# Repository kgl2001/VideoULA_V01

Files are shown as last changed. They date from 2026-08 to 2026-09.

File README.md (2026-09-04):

# VideoULA V01 — BBC Micro Video ULA Replacement
## 44-pin Xilinx XC9572XL CPLD Version

This repository contains the hardware design and firmware for the VideoULA V01, a drop-in replacement for the VC2069 Video ULA (IC6) in the Acorn BBC Micro Model B.

---

## Project Overview

The original BBC Micro Video ULA (IC6) is a custom ASIC that is no longer manufactured. Failed or missing ULAs result in a non-functional machine. This project provides a modern replacement using a CPLD and a small external SRAM for palette storage.

There are three hardware versions of this replacement, each in a separate repository:

| Version | CPLD | Macrocells | Tool | Repository |
|---|---|---|---|---|
| **V01** | Xilinx XC9572XL-10-VQ44 | 72 | ISE 14.7 | This repo |
| V02 | Xilinx XC9572XL-10-VQ64 | 72 | ISE 14.7 | [VideoULA_V02](https://github.com/kgl2001/VideoULA_V02) |
| V03 | Atmel ATF1504AS-10AU44 | 64 | Quartus 13.0 SP1 | [VideoULA_V03](https://github.com/kgl2001/VideoULA_V03) |

All three versions share the same 28-pin DIP footprint as the original ULA and are pin-compatible with the BBC Micro motherboard.

---

## V01 Hardware

- **CPLD**: Xilinx XC9572XL-10-VQ44 (72 macrocells, 3.3V core, 5V tolerant I/O)
- **SRAM**: ISSI IS62C256AL-45TLI (32K×8, 5V, TSOP-28, 45ns) — only locations 0-15 and bits 0-3 used
- **Oscillator**: 48MHz SMD oscillator (3225 package, 5V) — for 48MHz operating mode only
- **LDO**: XC6206P332MR (SOT-23, 3.3V) — powers CPLD core

### Hardware Revisions

| Revision | Status | Changes |
|---|---|---|
| Rev01 | Built and tested | Initial release |
| Rev02 | PCB designed, not yet built | Added 47Ω series resistor and 74LVC1G17 Schmitt trigger buffer on CLK_IN; CPLD pin assignments updated |
| Rev03 | PCB designed, not yet built | Added 74LV6T17 to buffer all clock outputs (8/4/2/1MHz, CRTC) for Master 128 compatibility |
| Rev04 | PCB designed, not yet built | Repositioned JTAG header |

Note: Only Rev01 has been built and tested. Rev02 onwards incorporate improvements identified during Rev01 testing.

### CLK_IN Reliability Daughterboard

During testing of Rev01 on BBC Micro machines with the original 16MHz clock circuit, some machines showed reliability issues in 16MHz operating mode — particularly on cold startup. Investigation revealed that the BBC's 16MHz crystal oscillator circuit produces a noisy clock signal that the CPLD occasionally misinterprets as spurious edges, causing display glitches.

To address this without waiting for a new PCB revision, a small standalone buffer board was developed. This daughterboard:

- Plugs into the BBC Micro motherboard in place of the VideoULA V01
- The VideoULA V01 then plugs into the daughterboard
- Intercepts the 16MHz clock signal from the BBC motherboard
- Passes it through a 47Ω series resistor and 74HCT14E Schmitt trigger buffer before it reaches the CPLD
- Passes all other signals through unchanged

The 74HCT14E was chosen as a through-hole part for ease of hand soldering. Rev02+ PCB designs use the smaller surface-mount 74LVC1G17 in conjunction with a series resistor to achieve the same signal conditioning in a more compact form.

This fix was confirmed to resolve the cold startup reliability issues on affected machines. The improvement has been incorporated into Rev02 of the V01 PCB and all subsequent hardware versions.

The daughterboard design files are included in this repository.

---

## Firmware

The firmware is written in Verilog and built using Xilinx ISE 14.7.

### Operating Modes

Two firmware builds are required — one per operating mode. To switch modes, reprogram the CPLD with the appropriate `.jed` file. A solder bridge on the PCB selects whether the 48MHz oscillator or the BBC's 16MHz clock is connected to the CPLD clock input.

#### 48MHz Mode (recommended)
- Uses the onboard 48MHz oscillator as the master clock
- Generates all BBC clock outputs (8/4/2/1MHz, CRTC, 6MHz) internally
- Provides clean, phase-locked 6MHz output for the SAA5050 teletext chip (tD ≈ 20ns ✓)
- Works reliably on all machines from cold power-up, including those with noisy clock circuits
- Build: uncomment `` `define CLK_48MHZ `` in `VideoULA.v`

#### 16MHz Mode
- Uses the BBC motherboard's 16MHz clock as the master clock
- No onboard oscillator required
- May show brief display noise on cold startup on machines with noisy 16MHz clock circuits
- The CLK_IN daughterboard resolves this on Rev01; Rev02+ has the fix built in
- Build: uncomment `` `define CLK_16MHZ `` in `VideoULA.v`

### ISE Fitter Settings (critical)

| Setting | Value | Notes |
|---|---|---|
| Implementation Template | **Optimise Speed** | Density causes timing failures at temperature |
| Macrocell Power | **Std** | Low Power prevents BBC from booting |
| Output Slew Rate | Fast | |
| Default Powerup Value | Low | |
| Pterms | **14** (16MHz build only) | Default 25 causes silent fit failure in 16MHz build |

### Build Instructions

1. Open Xilinx ISE 14.7
2. Create a new project targeting `XC9572XL-10-VQ44`
3. Add `src/VideoULA.v` and `src/VideoULA.ucf` to the project
4. Select the operating mode by uncommenting the appropriate `define` in `VideoULA.v`
5. Set fitter options as above
6. Run `Implement Design` to generate the `.jed` file
7. Program the CPLD using iMPACT or a compatible JTAG programmer

---

## SRAM Wiring

The external SRAM stores the 16-entry colour palette (4 bits per entry):

| SRAM Pin | Connection |
|---|---|
| A0-A3 | CPLD SRAM_ADDR[0:3] |
| A4-A14 | GND (tie low) |
| D0-D3 | CPLD SRAM_DATA[0:3] (bidirectional) |
| D4-D7 | Leave unconnected |
| /WE | CPLD SRAM_nWE |
| /OE | GND (always output enabled) |
| /CS | GND (always selected) |

---

## 6MHz Clock for Mode 7 (Teletext)

The SAA5050 teletext chip requires a 6MHz clock with a specific phase relationship to the 1MHz system clock (tD = 6-60ns from 6MHz rising edge to 1MHz falling edge).

- **48MHz mode**: The CPLD generates a clean, phase-locked 6MHz output on the CLK_6M pin (tD ≈ 20ns ✓). This can be connected to the SAA5050 via an IC37 replacement board.
- **16MHz mode**: The BBC motherboard's existing 6MHz generation circuit is used. The CPLD CLK_6M output is held high-Z.

---

## PCB Design Notes

The PCB has been designed using KiCAD V10 as a 2-layer board. It can easily be changed to a 4-layer board with GND/Power planes on the inner layers if signal integrity is a concern.

### JLCPCB Fabrication

The board design includes a 5×5mm silkscreen box on the underside of the PCB. This is used by JLCPCB to position a QR code serial number. When ordering from JLCPCB:

- Select **Specify position** in the QR code / 2D barcode options during the ordering process
- If this option is not selected, JLCPCB will print the 5×5mm silkscreen box as-is and attempt to place the QR code at a different location of their choosing

If not using JLCPCB, the chosen fabricator will likely print the 5×5mm box as a plain white square on the PCB. To avoid this, remove the silkscreen box from the PCB design and regenerate the Gerber files before submitting.

### Assembly

A combined CPL (Component Placement List) and BOM (Bill of Materials) Excel file is included in the Gerbers folder. This can be used directly with the JLCPCB PCBA (PCB Assembly) service.

Note that the JLCPCB Economy PCBA process only assembles components on one side of the PCB. Select the **top side** for assembly — this leaves only the SRAM and its associated decoupling capacitor to be hand soldered to the underside of the board.

---

## Known Limitations

- **Cold startup noise (16MHz mode, standard clock machines)**: Machines with noisy 16MHz clock circuits may show brief display noise on cold power-up. Use the CLK_IN daughterboard (Rev01) or upgrade to Rev02+ which has the fix built in. The 48MHz operating mode is not affected.
- **Master 128 compatibility**: V01 has not been tested on the Master 128. Clock output buffering (added in Rev03) may be required for full Master 128 compatibility.
- **SCART/HDMI adapter compatibility**: Some SCART→HDMI display adapters may show minor pixel artefacts with non-standard screen modes. RGBtoHDMI and direct CRT connections are not affected.

---

## Compatibility

Tested on BBC Micro Model B with original clock circuit and with clock fixer modification. Not tested on BBC Master 128.

---

## Credits

- **Ken Lowe** — PCB design, Verilog development and testing
- **hoglet (Stardot forums)** — Clock architecture analysis, DRAM timing analysis, community testing
- **Stardot community** — Testing, feedback and suggestions

---

## Licence

Hardware: [Creative Commons BY-SA 4.0](https://creativecommons.org/licenses/by-sa/4.0/)

Firmware: [MIT Licence](https://opensource.org/licenses/MIT)

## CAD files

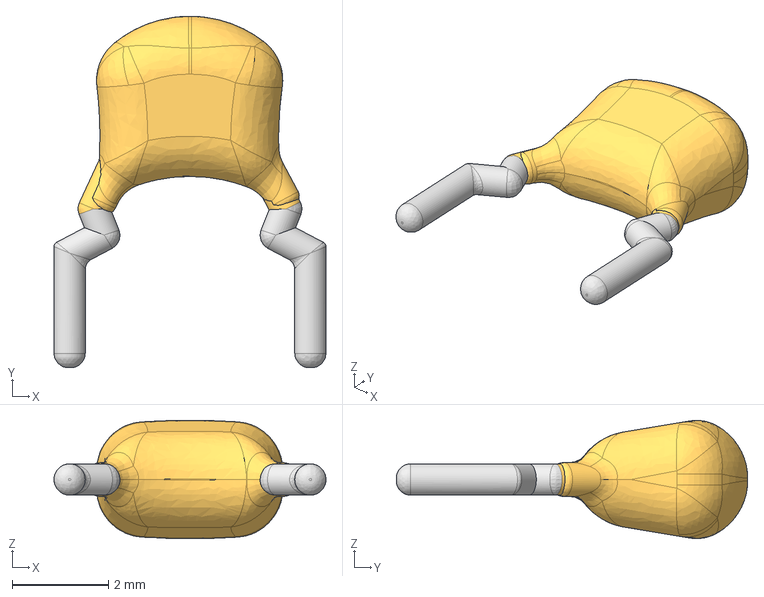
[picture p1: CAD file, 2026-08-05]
KiCAD Files/Rev01 - BufferBoard/3DModels/Ceramic Cap, 5mm lead spacing, 4mm width, and 5.5mm tall, v4 v2.step
5.65 x 7.30 x 2.46 mm

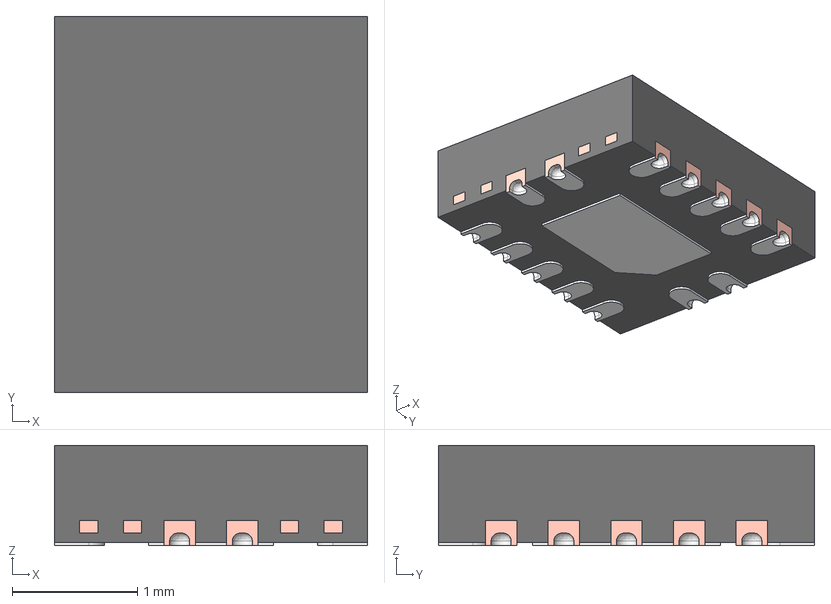
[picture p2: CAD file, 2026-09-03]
KiCAD Files/Rev04/3DModels/BQA0014B.stp
2.50 x 3.00 x 0.8 mm
FRAME
PIN1_AREA

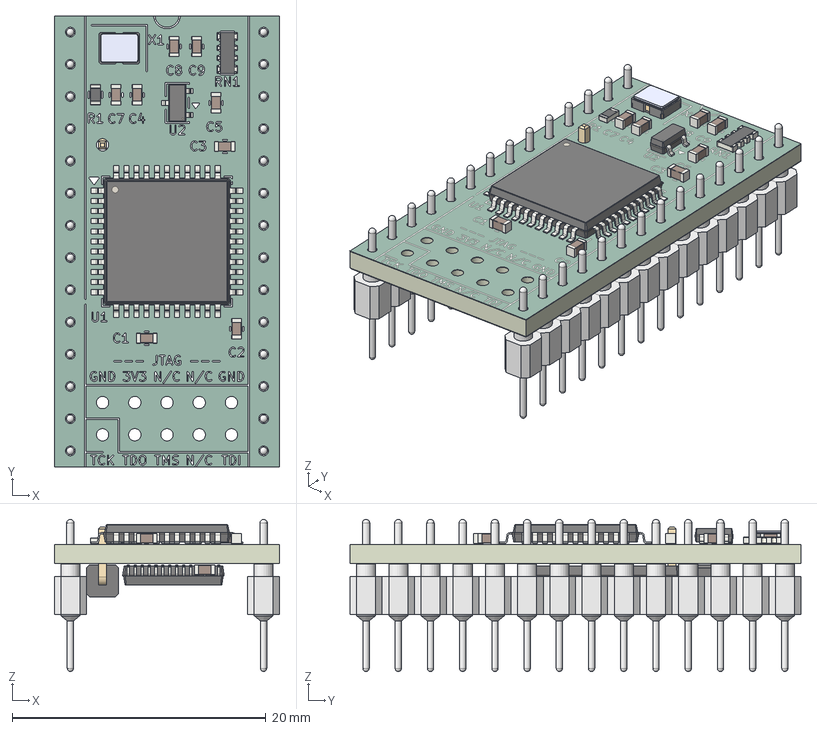
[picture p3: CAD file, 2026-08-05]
KiCAD Files/Rev01 - BufferBoard/3DModels/VideoULA.step
17.8 x 35.6 x 12.0 mm
C_0603_1608Metric x 9
R_0603_1608Metric
ECS-TXO-3225-100-TR
R_Array_Convex_4x0603
LQFP-44_10x10mm_P0.8mm
SOT-23-3
PinHeader_1x01_P254mm_Horizontal
TSOP-I-28_11.8x8mm_P0.55mm
VideoULA_silkscreen x 2
VideoULA_soldermask x 2
VideoULA_PCB

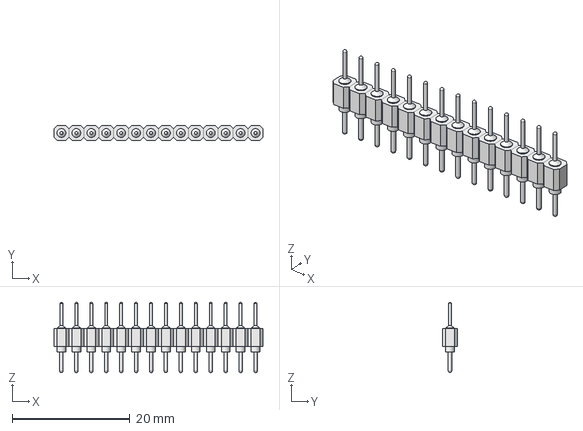
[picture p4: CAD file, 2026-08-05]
KiCAD Files/Rev04/3DModels/Header-Male-round 14 pin.step
35.6 x 2.54 x 12.0 mm

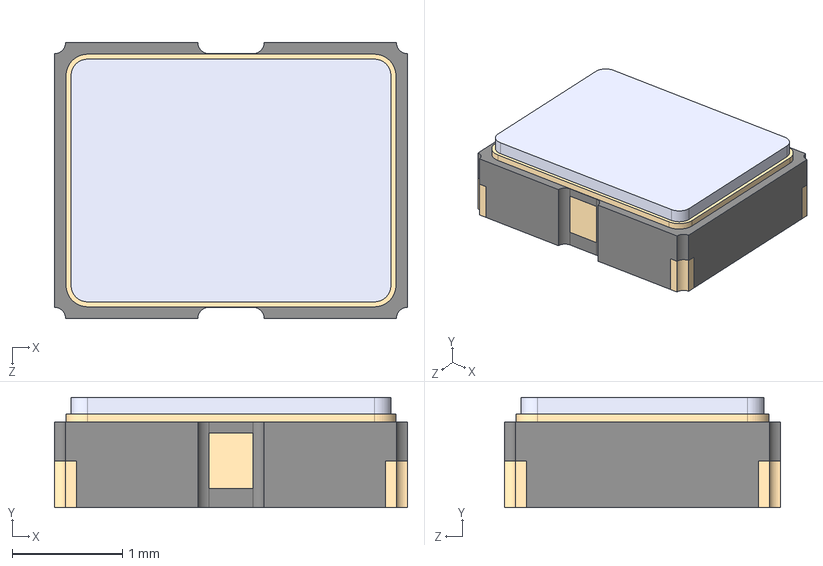
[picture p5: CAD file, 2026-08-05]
KiCAD Files/Rev04/3DModels/ECS-TXO-3225-250-TR.STEP
3.20 x 1.00 x 2.50 mm

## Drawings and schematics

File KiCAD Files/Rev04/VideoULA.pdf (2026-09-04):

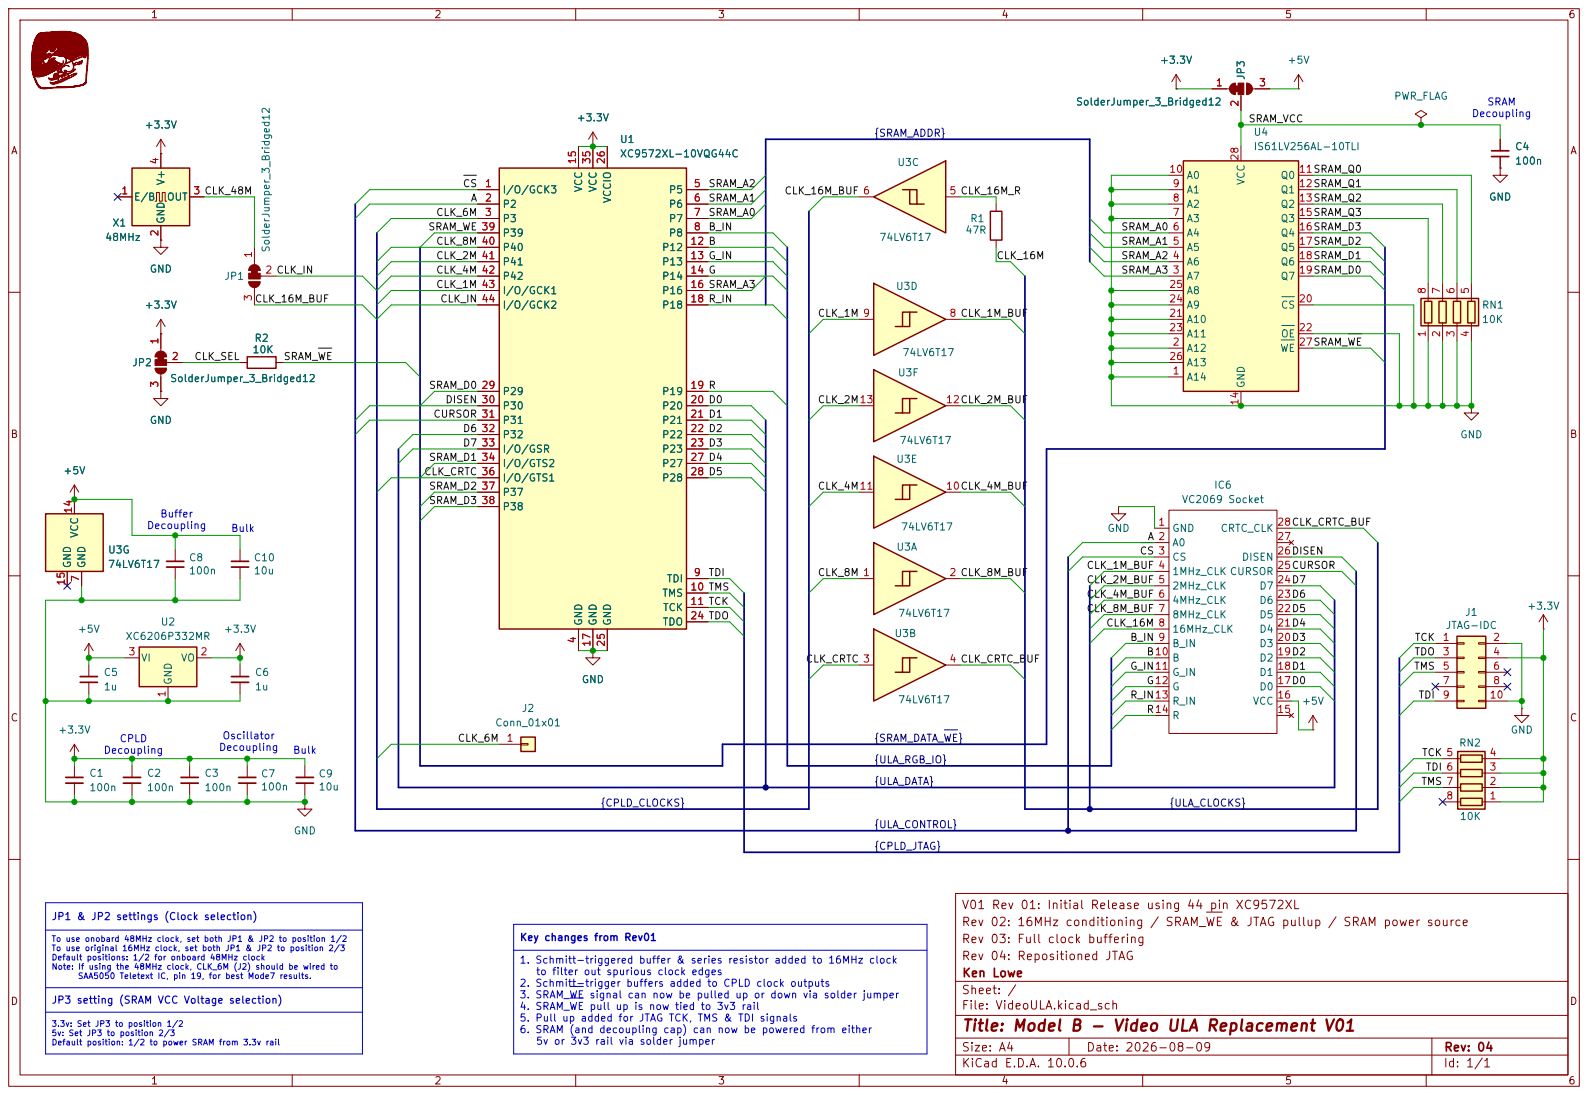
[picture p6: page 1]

A1 9 | SRAM_Q1
A2 8 | SRAM_Q2

Rev 02: 16MHz conditioning / SRAM_WE & JTAG pullup / SRAM power source
Rev 03: Full clock buffering
Rev 04: Repositioned JTAG
Ken Lowe
Sheet: /
File: VideoULA.kicad_sch
Title: Model B - Video ULA Replacement V01

To use onobard 48MHz clock, set both JP1 & JP2 to position 1/2
To use original 16MHz clock, set both JP1 & JP2 to position 2/3 Default positions: 1/2 for onboard 48MHz clock Note: If using the 48MHz clock, CLK_6M (J2) should be wired to SAA5050 Teletext IC, pin 19, for best Mode7 results. JP3 setting (SRAM VCC Voltage selection) 3.3v: Set JP3 to position 1/2

1. Schmitt-triggered buffer & series resistor added to 16MHz clock
to filter out spurious clock edges 2. Schmitt-trigger buffers added to CPLD clock outputs 3. SRAM_WE signal can now be pulled up or down via solder jumper 4. SRAM_WE pull up is now tied to 3v3 rail 5. Pull up added for JTAG TCK, TMS & TDI signals 6. SRAM (and decoupling cap) can now be powered from either 5v or 3v3 rail via solder jumper

Size: A4 | Rev: 04
KiCad E.D.A. 10.0.6 | Id: 1/1

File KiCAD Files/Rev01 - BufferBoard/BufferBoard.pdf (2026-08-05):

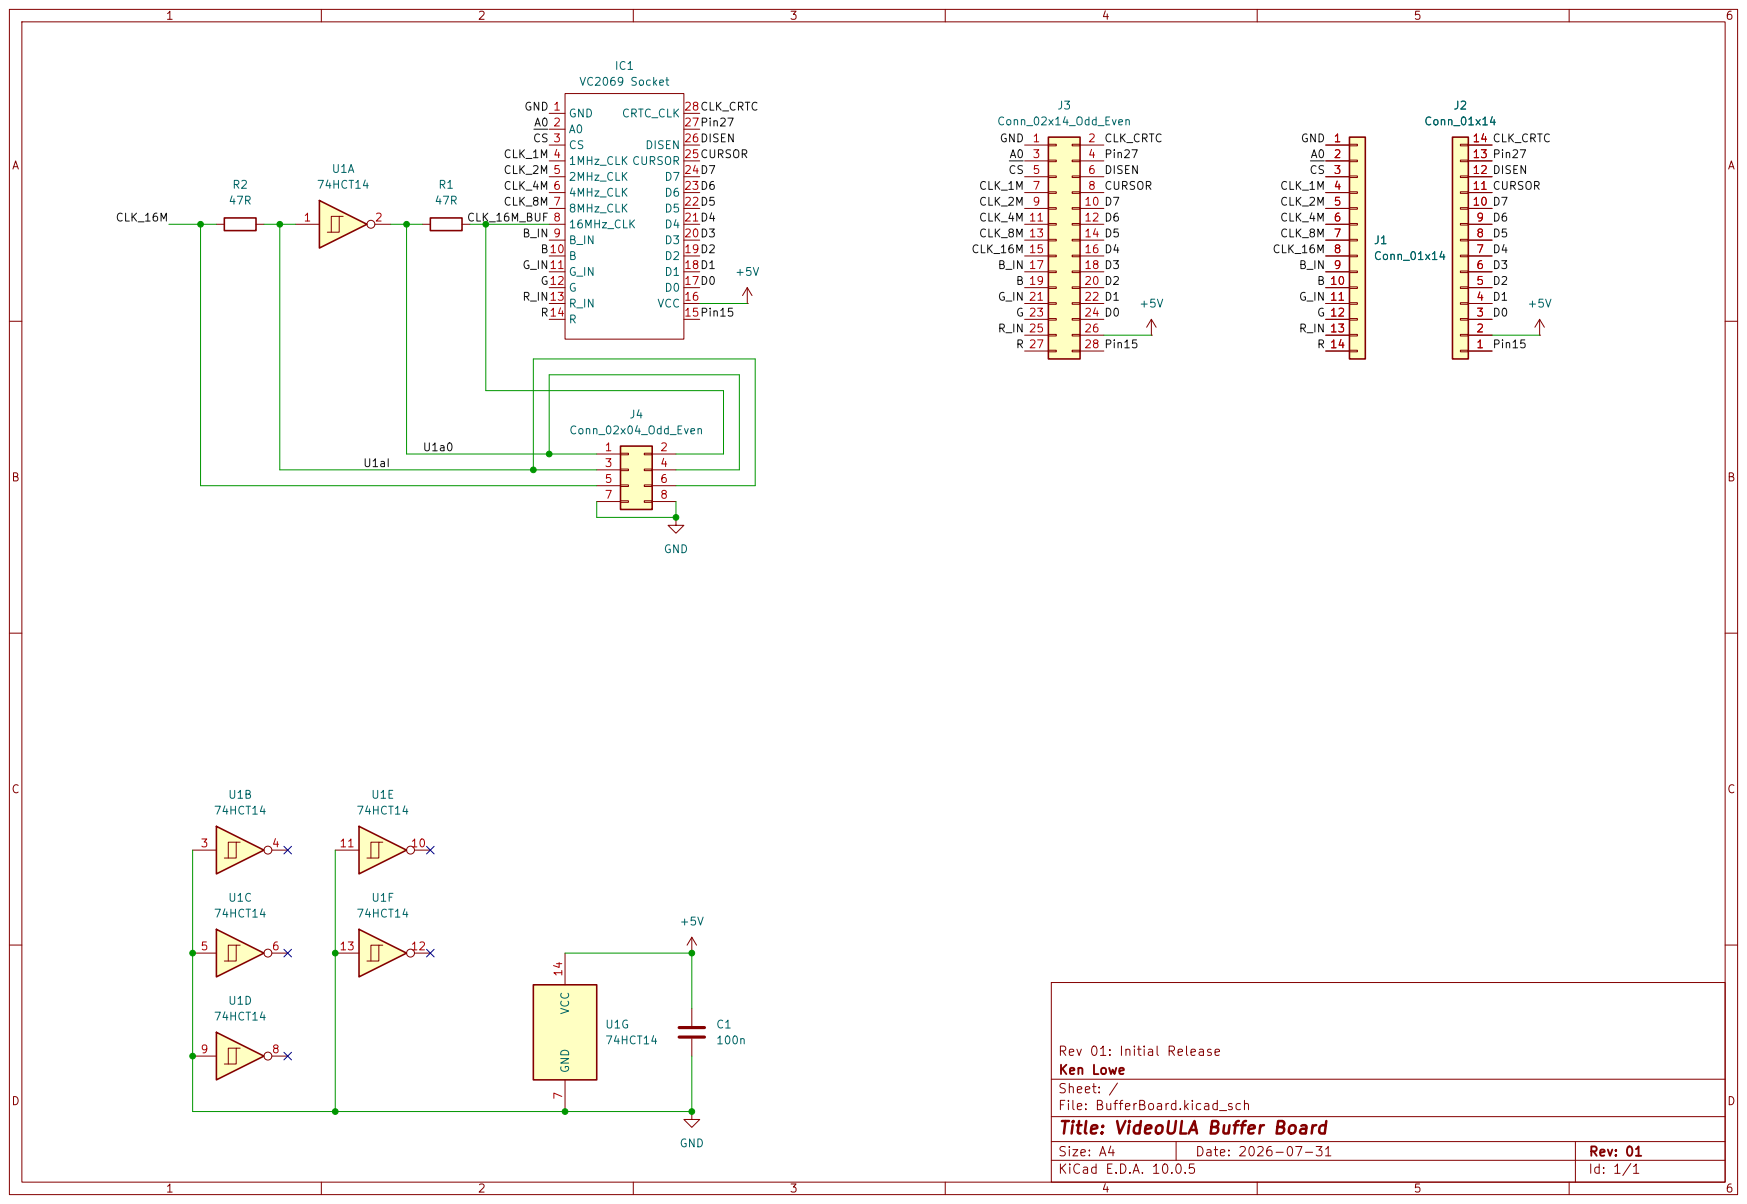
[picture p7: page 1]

Rev 01: Initial Release
Ken Lowe
Sheet: /
File: BufferBoard.kicad_sch
Title: VideoULA Buffer Board

Size: A4 | Rev: 01
KiCad E.D.A. 10.0.5 | Id: 1/1

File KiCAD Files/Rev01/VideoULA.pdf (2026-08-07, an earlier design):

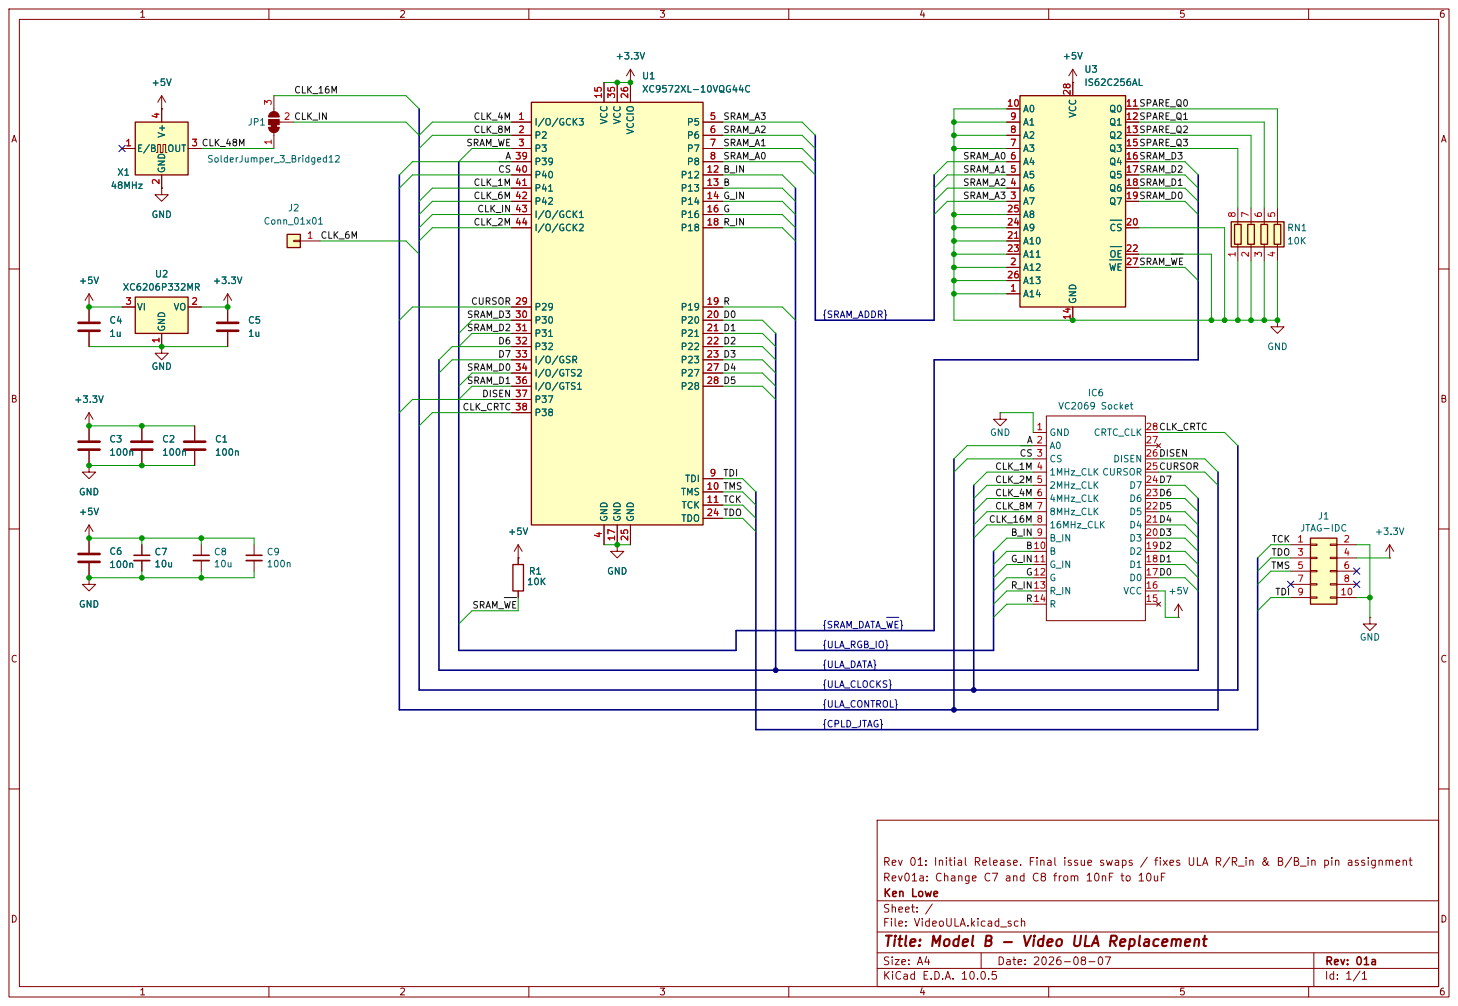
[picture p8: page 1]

Rev 01: Initial Release. Final issue swaps / fixes ULA R/R_in & B/B_in pin assignment
Rev01a: Change C7 and C8 from 10nF to 10uF
Ken Lowe
Sheet: /
File: VideoULA.kicad_sch
Title: Model B - Video ULA Replacement

Size: A4 | Rev: 01a
KiCad E.D.A. 10.0.5 | Id: 1/1

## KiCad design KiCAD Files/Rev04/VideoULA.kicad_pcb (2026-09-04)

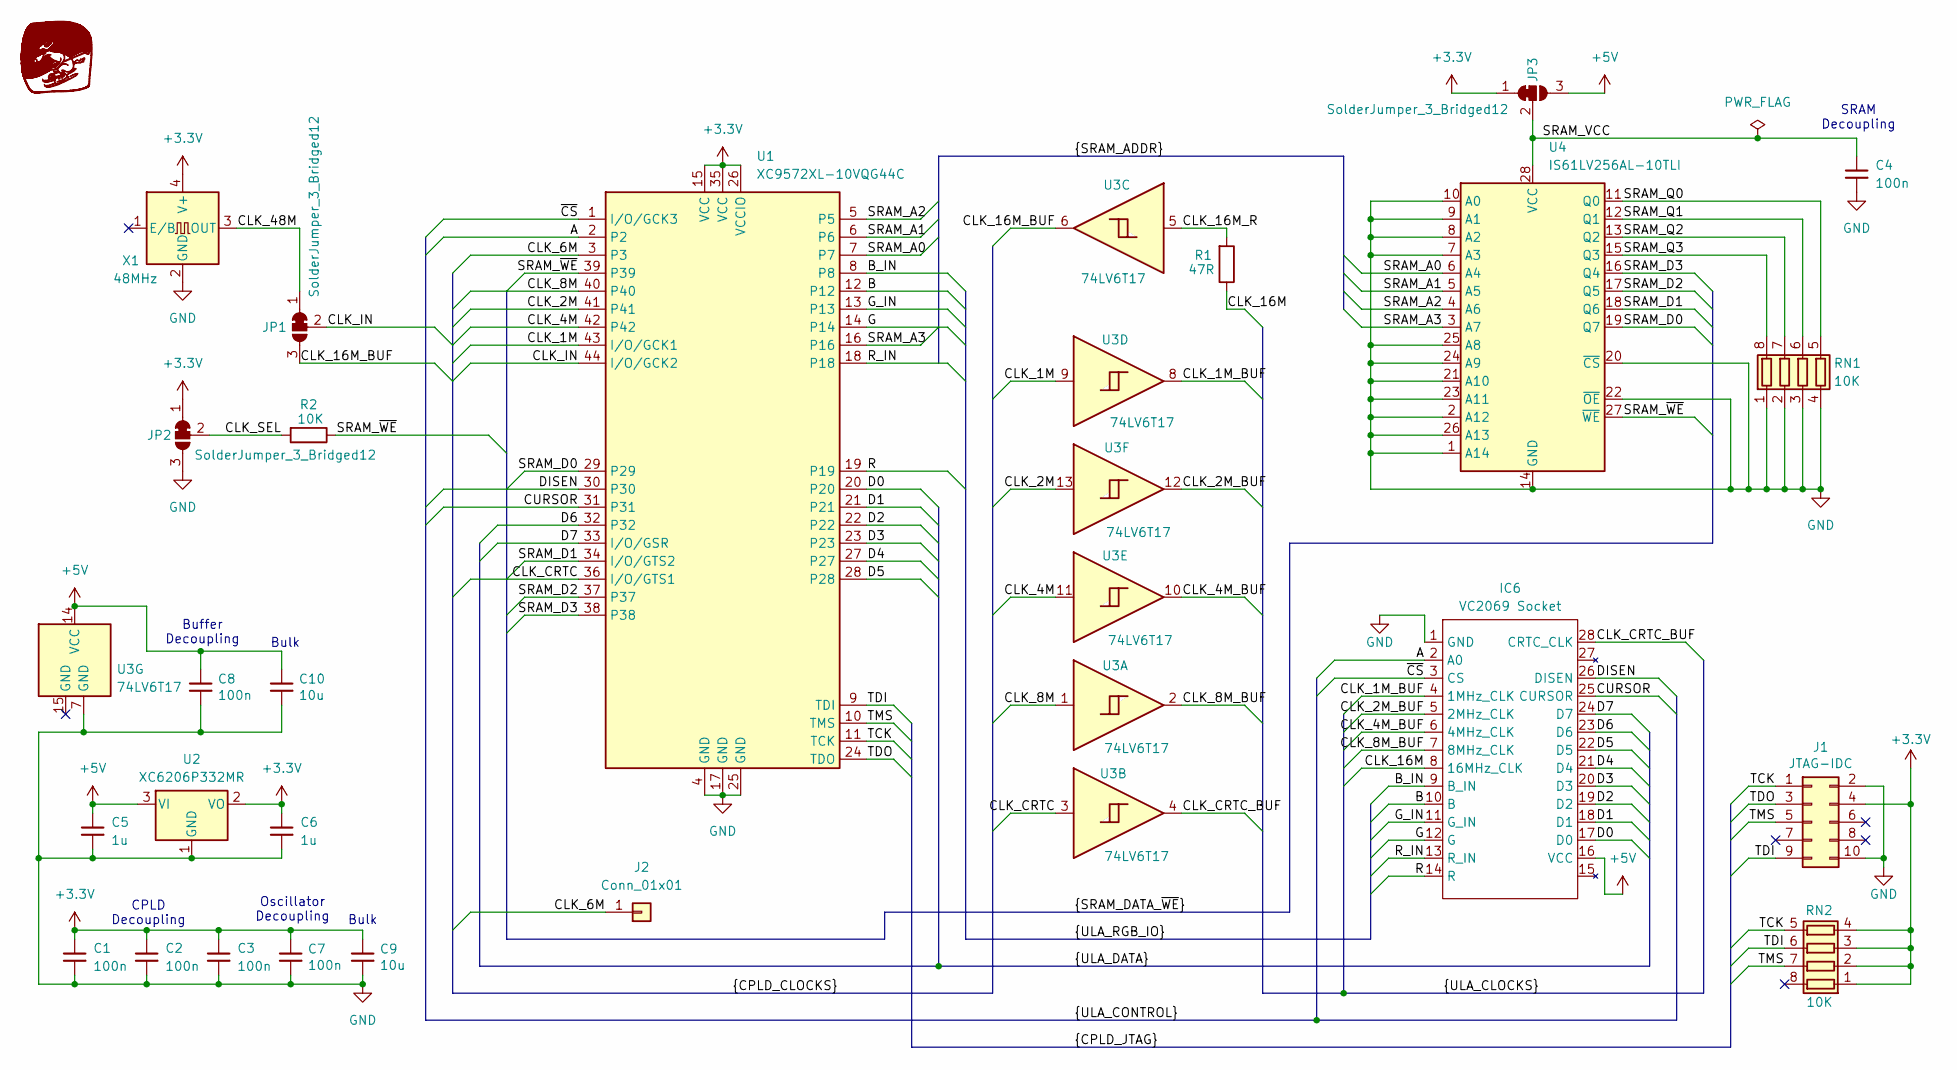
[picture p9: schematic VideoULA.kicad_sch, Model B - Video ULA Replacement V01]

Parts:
C1, C2, C3, C4, C7, C8: 100n; C_0603_1608Metric; JLC Part Number C14663
C5, C6: 1u; C_0603_1608Metric; JLC Part Number C15849
C9, C10: 10u; C_0603_1608Metric; JLC Part Number C19702
G1: Skidog; skidog_inv
IC6: VC2069 Socket; DIP-28_W15.24mm
J1: JTAG-IDC; PinHeader_2x05_P2.54mm_Vertical
J2: Conn_01x01; PinHeader_1x01_P2.54mm_Horizontal
JP1, JP2, JP3: SolderJumper_3_Bridged12; SolderJumper-3_P1.3mm_Bridged12_RoundedPad1.0x1.5mm
R1: 47R; R_0603_1608Metric; JLC Part Number C23182
R2: 10K; R_0603_1608Metric; JLC Part Number C25804
RN1, RN2: 10K; R_Array_Convex_4x0603; JLC Part Number C29718
U1: XC9572XL-10VQG44C; LQFP-44_10x10mm_P0.8mm; JLC Part Number C569042
U2: XC6206P332MR; SOT-23-3; JLC Part Number C5446
U3: 74LV6T17; DHWQFN-14-1EP_2.5x3mm_P0.5mm_EP1x1.5mm_ThermalVias; JLC Part Number C22428345
U4: IS61LV256AL-10TLI; TSOP-I-28_11.8x8mm_P0.55mm_SRAM; JLC Part Number C2062662
X1: 48MHz; Oscillator_SMD_Yajingxin_TFOM48M4RHKCNT2T-4Pin_3.2x2.5mm; JLC Part Number C454614

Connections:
+3.3V: C1.1, C2.1, C3.1, C6.1, C7.1, C9.1, J1.4, JP2.1 (A), JP3.1 (A), RN2.1 (R1.1), RN2.2 (R2.1), RN2.3 (R3.1), RN2.4 (R4.1), U1.15 (VCC), U1.26 (VCCIO), U1.35 (VCC), U2.2 (VO), X1.4 (V+)
+5V: C5.1, C8.1, C10.1, IC6.16 (VCC), JP3.3 (B), U2.3 (VI), U3.14 (VCC)
/A: IC6.2 (A0), U1.2
/B: IC6.10 (B), U1.12
/B_IN: IC6.9 (B_IN), U1.8
/CLK_1M: U1.43 (I/O/GCK1), U3.9
/CLK_1M_BUF: IC6.4 (1MHz_CLK), U3.8
/CLK_2M: U1.41, U3.13
/CLK_2M_BUF: IC6.5 (2MHz_CLK), U3.12
/CLK_4M: U1.42, U3.11
/CLK_4M_BUF: IC6.6 (4MHz_CLK), U3.10
/CLK_6M: J2.1 (Pin_1_1), U1.3
/CLK_8M: U1.40, U3.1
/CLK_8M_BUF: IC6.7 (8MHz_CLK), U3.2
/CLK_16M: IC6.8 (16MHz_CLK), R1.1
/CLK_16M_BUF: JP1.3 (B), U3.6
/CLK_16M_R: R1.2, U3.5
/CLK_48M: JP1.1 (A), X1.3 (OUT)
/CLK_CRTC: U1.36 (I/O/GTS1), U3.3
/CLK_CRTC_BUF: IC6.28 (CRTC_CLK), U3.4
/CLK_IN: JP1.2 (C), U1.44 (I/O/GCK2)
/CLK_SEL: JP2.2 (C), R2.2
/CURSOR: IC6.25 (CURSOR), U1.31
/D0: IC6.17 (D0), U1.20
/D1: IC6.18 (D1), U1.21
/D2: IC6.19 (D2), U1.22
/D3: IC6.20 (D3), U1.23
/D4: IC6.21 (D4), U1.27
/D5: IC6.22 (D5), U1.28
/D6: IC6.23 (D6), U1.32
/D7: IC6.24 (D7), U1.33 (I/O/GSR)
/DISEN: IC6.26 (DISEN), U1.30
/G: IC6.12 (G), U1.14
/G_IN: IC6.11 (G_IN), U1.13
/R: IC6.14 (R), U1.19
/R_IN: IC6.13 (R_IN), U1.18
/SRAM_A0: U1.7, U4.6 (A4)
/SRAM_A1: U1.6, U4.5 (A5)
/SRAM_A2: U1.5, U4.4 (A6)
/SRAM_A3: U1.16, U4.3 (A7)
/SRAM_D0: U1.29, U4.19 (Q7)
/SRAM_D1: U1.34 (I/O/GTS2), U4.18 (Q6)
/SRAM_D2: U1.37, U4.17 (Q5)
/SRAM_D3: U1.38, U4.16 (Q4)
/SRAM_Q0: RN1.5 (R4.2), U4.11 (Q0)
/SRAM_Q1: RN1.6 (R3.2), U4.12 (Q1)
/SRAM_Q2: RN1.7 (R2.2), U4.13 (Q2)
/SRAM_Q3: RN1.8 (R1.2), U4.15 (Q3)
/SRAM_VCC: C4.1, JP3.2 (C), U4.28 (VCC)
/SRAM_~WE: R2.1, U1.39, U4.27 (~WE)
/TCK: J1.1, RN2.5 (R4.2), U1.11 (TCK)
/TDI: J1.9, RN2.6 (R3.2), U1.9 (TDI)
/TDO: J1.3, U1.24 (TDO)
/TMS: J1.5, RN2.7 (R2.2), U1.10 (TMS)
/~CS: IC6.3 (CS), U1.1 (I/O/GCK3)
GND: C1.2, C2.2, C3.2, C4.2, C5.2, C6.2, C7.2, C8.2, C9.2, C10.2, IC6.1 (GND), J1.2, J1.10, JP2.3 (B), RN1.1 (R1.1), RN1.2 (R2.1), RN1.3 (R3.1), RN1.4 (R4.1), U1.4 (GND), U1.17 (GND), U1.25 (GND), U2.1 (GND), U3.7 (GND), U4.1 (A14), U4.2 (A12), U4.7 (A3), U4.8 (A2), U4.9 (A1), U4.10 (A0), U4.14 (GND), U4.20 (~CS), U4.21 (A10), U4.22 (~OE), U4.23 (A11), U4.24 (A9), U4.25 (A8), U4.26 (A13), X1.2 (GND)

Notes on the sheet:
SRAM Decoupling
Oscillator Decoupling
CPLD Decoupling
Bulk
Buffer Decoupling

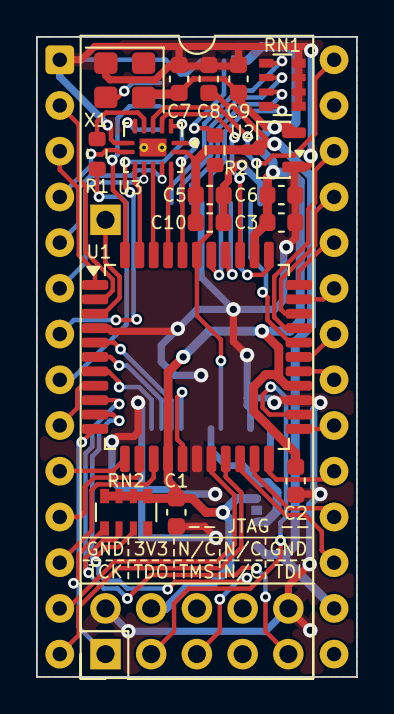
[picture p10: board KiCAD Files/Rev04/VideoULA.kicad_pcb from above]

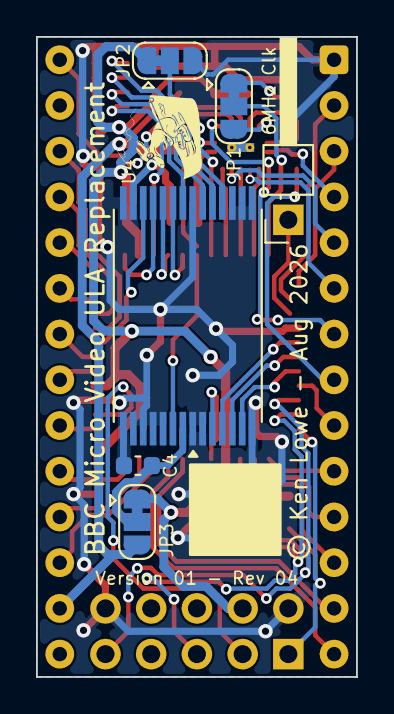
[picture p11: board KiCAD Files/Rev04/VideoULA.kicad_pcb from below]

Board: 2 copper layers, 17.8 x 35.6 mm, 26 parts (7 on the bottom side), 56 nets.

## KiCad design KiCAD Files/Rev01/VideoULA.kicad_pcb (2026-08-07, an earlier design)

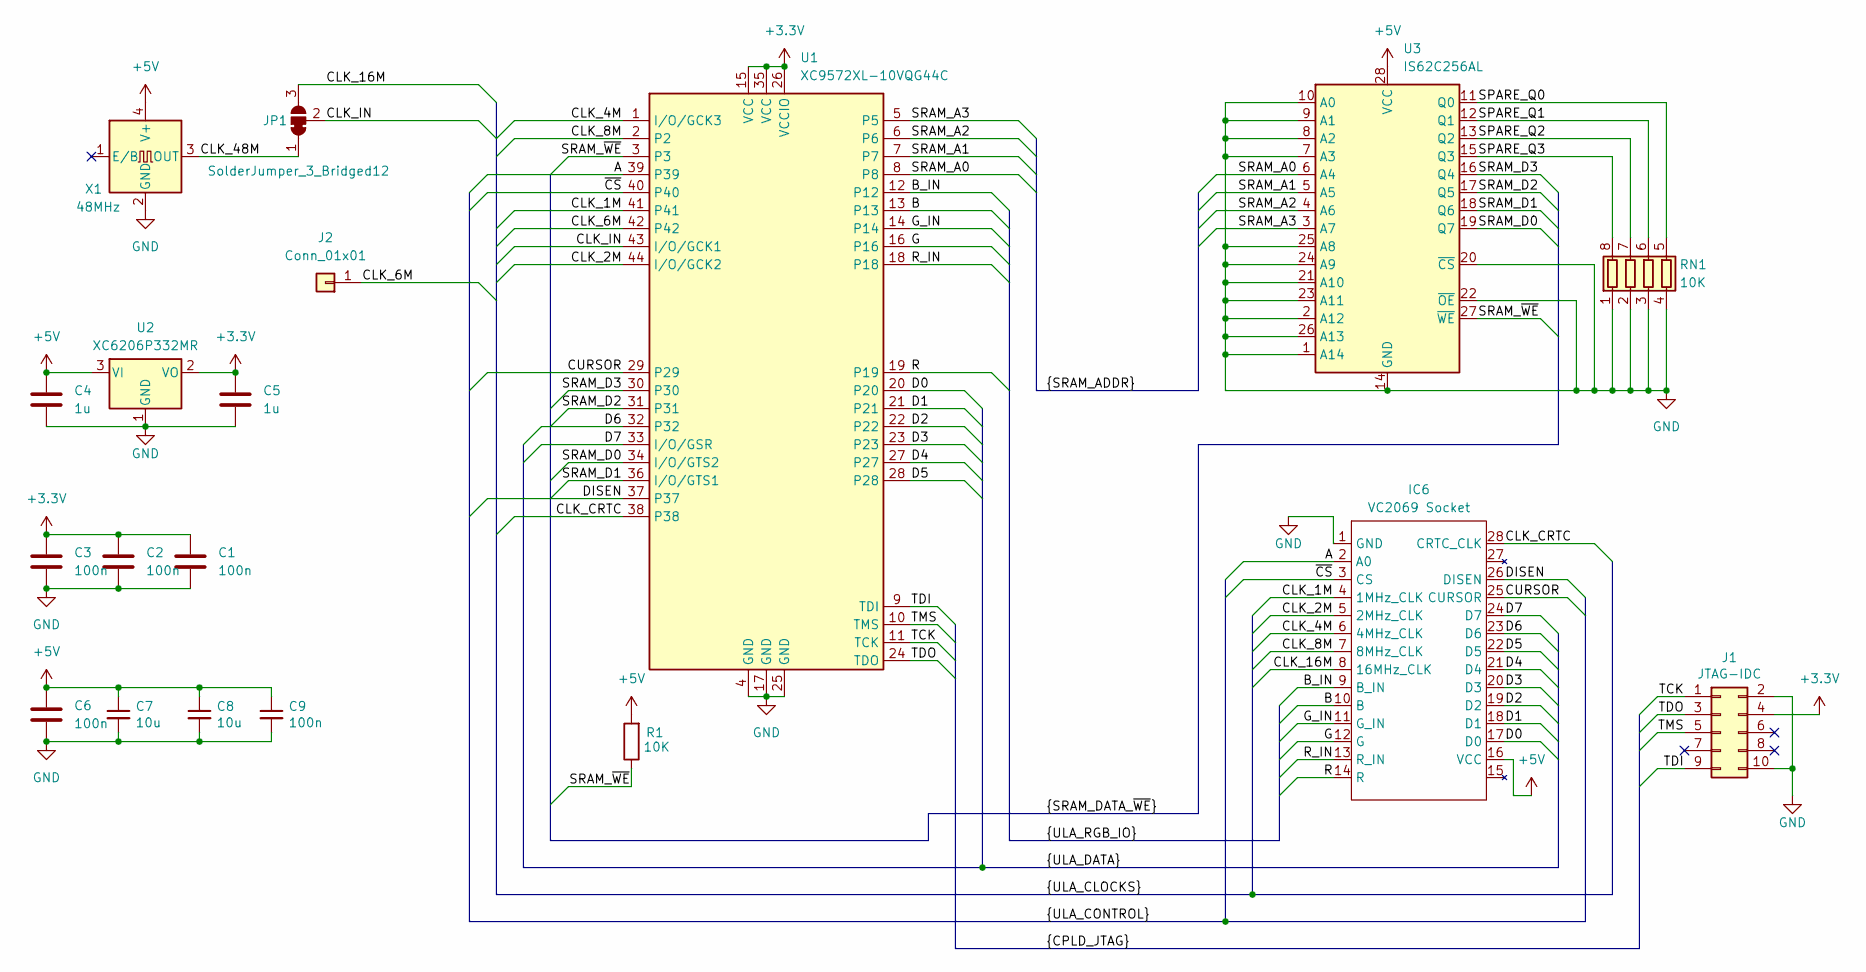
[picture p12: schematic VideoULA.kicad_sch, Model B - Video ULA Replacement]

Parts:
C1, C2, C3, C6, C9: 100n; C_0603_1608Metric; JLC Part Number C14663
C4, C5: 1u; C_0603_1608Metric; JLC Part Number C15849
C7, C8: 10u; C_0603_1608Metric; JLC Part Number C19702
IC6: VC2069 Socket; DIP-28_W15.24mm
J1: JTAG-IDC; PinHeader_2x05_P2.54mm_Vertical
J2: Conn_01x01; PinHeader_1x01_P2.54mm_Horizontal
JP1: SolderJumper_3_Bridged12; SolderJumper-3_P1.3mm_Bridged12_RoundedPad1.0x1.5mm
R1: 10K; R_0603_1608Metric; JLC Part Number C25804
RN1: 10K; R_Array_Convex_4x0603; JLC Part Number C29718
U1: XC9572XL-10VQG44C; LQFP-44_10x10mm_P0.8mm; JLC Part Number C569042
U2: XC6206P332MR; SOT-23-3; JLC Part Number C5446
U3: IS62C256AL; TSOP-I-28_11.8x8mm_P0.55mm_SRAM; JLC Part Number C47143
X1: 48MHz; Oscillator_SMD_Yajingxin_TFOM48M4RHKCNT2T-4Pin_3.2x2.5mm; JLC Part Number C454614

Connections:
+3.3V: C1.1, C2.1, C3.1, C5.1, J1.4, U1.15 (VCC), U1.26 (VCCIO), U1.35 (VCC), U2.2 (VO)
+5V: C4.1, C6.1, C7.1, C8.1, C9.1, IC6.16 (VCC), R1.2, U2.3 (VI), U3.28 (VCC), X1.4 (V+)
/A: IC6.2 (A0), U1.39
/B: IC6.10 (B), U1.13
/B_IN: IC6.9 (B_IN), U1.12
/CLK_1M: IC6.4 (1MHz_CLK), U1.41
/CLK_2M: IC6.5 (2MHz_CLK), U1.44 (I/O/GCK2)
/CLK_4M: IC6.6 (4MHz_CLK), U1.1 (I/O/GCK3)
/CLK_6M: J2.1 (Pin_1_1), U1.42
/CLK_8M: IC6.7 (8MHz_CLK), U1.2
/CLK_16M: IC6.8 (16MHz_CLK), JP1.3 (B)
/CLK_48M: JP1.1 (A), X1.3 (OUT)
/CLK_CRTC: IC6.28 (CRTC_CLK), U1.38
/CLK_IN: JP1.2 (C), U1.43 (I/O/GCK1)
/CURSOR: IC6.25 (CURSOR), U1.29
/D0: IC6.17 (D0), U1.20
/D1: IC6.18 (D1), U1.21
/D2: IC6.19 (D2), U1.22
/D3: IC6.20 (D3), U1.23
/D4: IC6.21 (D4), U1.27
/D5: IC6.22 (D5), U1.28
/D6: IC6.23 (D6), U1.32
/D7: IC6.24 (D7), U1.33 (I/O/GSR)
/DISEN: IC6.26 (DISEN), U1.37
/G: IC6.12 (G), U1.16
/G_IN: IC6.11 (G_IN), U1.14
/R: IC6.14 (R), U1.19
/R_IN: IC6.13 (R_IN), U1.18
/SPARE_Q0: RN1.5 (R4.2), U3.11 (Q0)
/SPARE_Q1: RN1.6 (R3.2), U3.12 (Q1)
/SPARE_Q2: RN1.7 (R2.2), U3.13 (Q2)
/SPARE_Q3: RN1.8 (R1.2), U3.15 (Q3)
/SRAM_A0: U1.8, U3.6 (A4)
/SRAM_A1: U1.7, U3.5 (A5)
/SRAM_A2: U1.6, U3.4 (A6)
/SRAM_A3: U1.5, U3.3 (A7)
/SRAM_D0: U1.34 (I/O/GTS2), U3.19 (Q7)
/SRAM_D1: U1.36 (I/O/GTS1), U3.18 (Q6)
/SRAM_D2: U1.31, U3.17 (Q5)
/SRAM_D3: U1.30, U3.16 (Q4)
/SRAM_~WE: R1.1, U1.3, U3.27 (~WE)
/TCK: J1.1, U1.11 (TCK)
/TDI: J1.9, U1.9 (TDI)
/TDO: J1.3, U1.24 (TDO)
/TMS: J1.5, U1.10 (TMS)
/~CS: IC6.3 (CS), U1.40
GND: C1.2, C2.2, C3.2, C4.2, C5.2, C6.2, C7.2, C8.2, C9.2, IC6.1 (GND), J1.2, J1.10, RN1.1 (R1.1), RN1.2 (R2.1), RN1.3 (R3.1), RN1.4 (R4.1), U1.4 (GND), U1.17 (GND), U1.25 (GND), U2.1 (GND), U3.1 (A14), U3.2 (A12), U3.7 (A3), U3.8 (A2), U3.9 (A1), U3.10 (A0), U3.14 (GND), U3.20 (~CS), U3.21 (A10), U3.22 (~OE), U3.23 (A11), U3.24 (A9), U3.25 (A8), U3.26 (A13), X1.2 (GND)

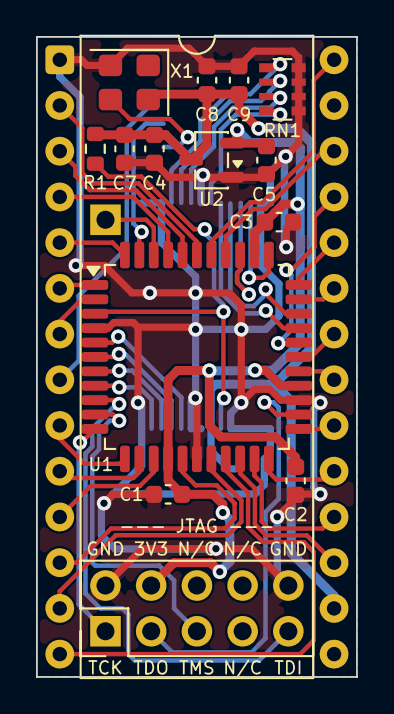
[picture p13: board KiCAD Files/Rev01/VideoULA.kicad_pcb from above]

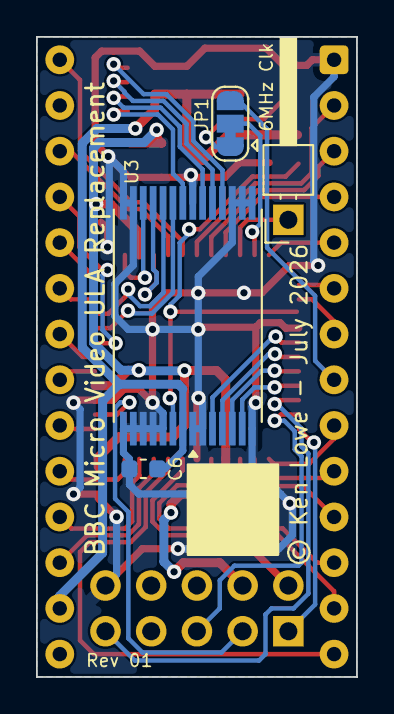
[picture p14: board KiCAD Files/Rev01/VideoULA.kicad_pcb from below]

Board: 2 copper layers, 17.8 x 35.6 mm, 19 parts (4 on the bottom side), 47 nets.

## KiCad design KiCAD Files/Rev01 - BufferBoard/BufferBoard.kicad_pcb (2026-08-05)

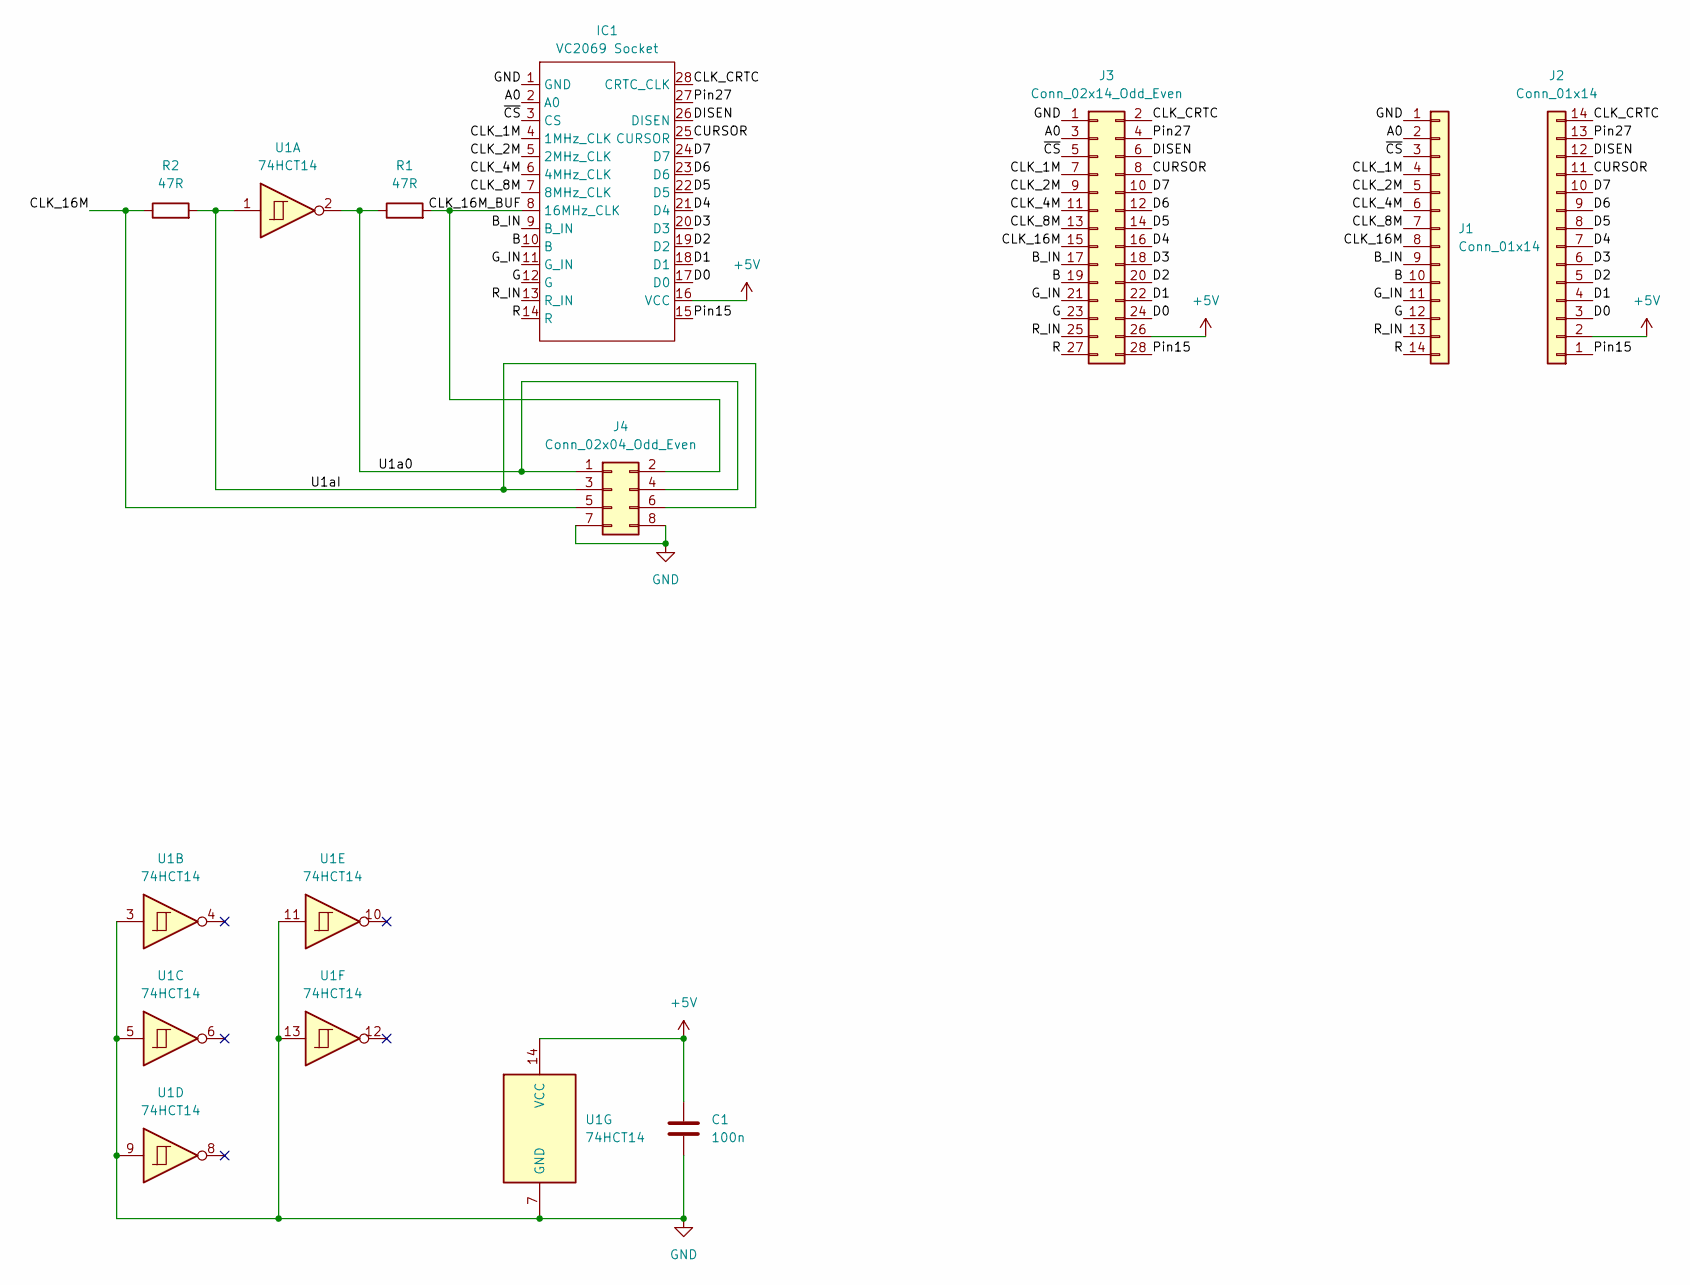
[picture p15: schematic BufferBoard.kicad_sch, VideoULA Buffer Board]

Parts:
C1: 100n; C_Disc_D4.3mm_W1.9mm_P5.00mm; JLC Part Number C14663
IC1: VC2069 Socket; DIP-28_W15.24mm_Socket
J1, J2: Conn_01x14; PinHeader_1x14_P2.54mm_Vertical
J3: Conn_02x14_Odd_Even; PinHeader_2x14_P2.54mm_Vertical
J4: Conn_02x04_Odd_Even; PinHeader_2x04_P2.54mm_Vertical
R1, R2: 47R; R_Axial_DIN0207_L6.3mm_D2.5mm_P10.16mm_Horizontal
U1: 74HCT14; DIP-14_W7.62mm_Socket

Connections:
+5V: C1.1, IC1.16 (VCC), J2.2, J3.26, U1.14 (VCC)
/A0: IC1.2 (A0), J1.2, J3.3
/B: IC1.10 (B), J1.10, J3.19
/B_IN: IC1.9 (B_IN), J1.9, J3.17
/CLK_1M: IC1.4 (1MHz_CLK), J1.4, J3.7
/CLK_2M: IC1.5 (2MHz_CLK), J1.5, J3.9
/CLK_4M: IC1.6 (4MHz_CLK), J1.6, J3.11
/CLK_8M: IC1.7 (8MHz_CLK), J1.7, J3.13
/CLK_16M: J1.8, J3.15, J4.5, R2.1
/CLK_16M_BUF: IC1.8 (16MHz_CLK), J4.2, R1.2
/CLK_CRTC: IC1.28 (CRTC_CLK), J2.14, J3.2
/CURSOR: IC1.25 (CURSOR), J2.11, J3.8
/D0: IC1.17 (D0), J2.3, J3.24
/D1: IC1.18 (D1), J2.4, J3.22
/D2: IC1.19 (D2), J2.5, J3.20
/D3: IC1.20 (D3), J2.6, J3.18
/D4: IC1.21 (D4), J2.7, J3.16
/D5: IC1.22 (D5), J2.8, J3.14
/D6: IC1.23 (D6), J2.9, J3.12
/D7: IC1.24 (D7), J2.10, J3.10
/DISEN: IC1.26 (DISEN), J2.12, J3.6
/G: IC1.12 (G), J1.12, J3.23
/G_IN: IC1.11 (G_IN), J1.11, J3.21
/Pin15: IC1.15, J2.1, J3.28
/Pin27: IC1.27, J2.13, J3.4
/R: IC1.14 (R), J1.14, J3.27
/R_IN: IC1.13 (R_IN), J1.13, J3.25
/U1a0: J4.1, J4.4, R1.1, U1.2
/U1aI: J4.3, J4.6, R2.2, U1.1
/~CS: IC1.3 (CS), J1.3, J3.5
GND: C1.2, IC1.1 (GND), J1.1, J3.1, J4.7, J4.8, U1.3, U1.5, U1.7 (GND), U1.9, U1.11, U1.13

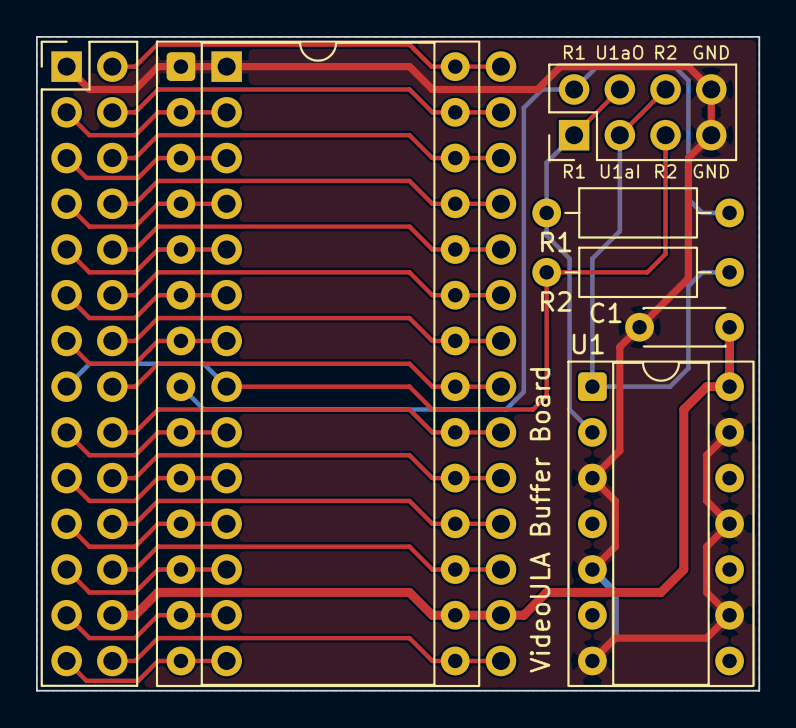
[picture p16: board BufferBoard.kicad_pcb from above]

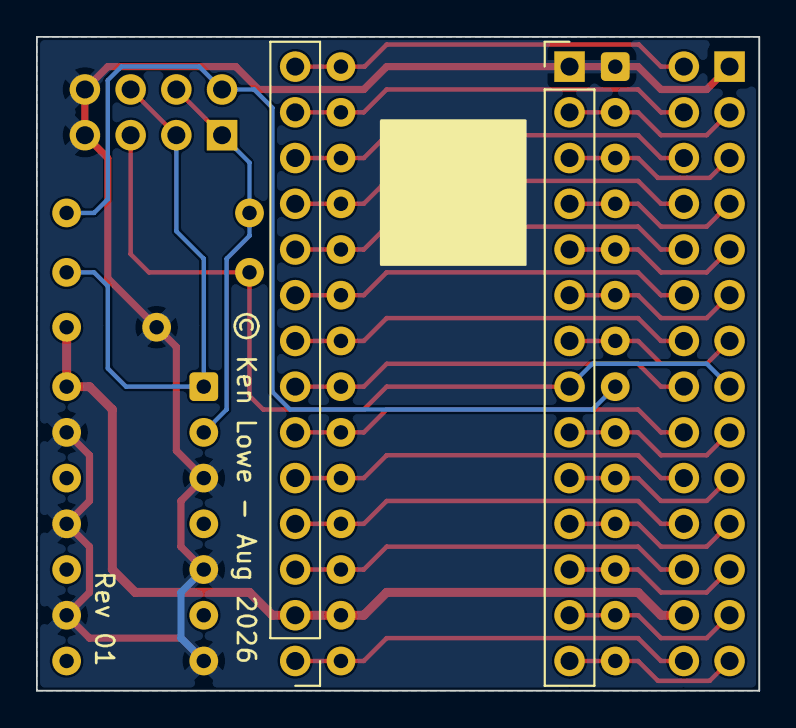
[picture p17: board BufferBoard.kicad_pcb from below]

Board: 2 copper layers, 40.1 x 36.3 mm, 9 parts (2 on the bottom side), 31 nets.

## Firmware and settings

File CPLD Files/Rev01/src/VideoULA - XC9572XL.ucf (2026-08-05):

#PACE: Start of Constraints generated by PACE
#PACE: Start of PACE I/O Pin Assignments
NET "A"  LOC = "P39"  ; 
NET "B"  LOC = "P13"  ; 
NET "B_IN"  LOC = "P12"  ; 
NET "CLK_IN"  LOC = "P43"  ; 
NET "CLK_1M"  LOC = "P41"  ; 
NET "CLK_2M"  LOC = "P44"  ; 
NET "CLK_4M"  LOC = "P1"  ; 
NET "CLK_8M"  LOC = "P2"  ; 
NET "CLK_CRTC"  LOC = "P38"  ; 
NET "CURSOR"  LOC = "P29"  ; 
NET "D<0>"  LOC = "P20"  ; 
NET "D<1>"  LOC = "P21"  ; 
NET "D<2>"  LOC = "P22"  ; 
NET "D<3>"  LOC = "P23"  ; 
NET "D<4>"  LOC = "P27"  ; 
NET "D<5>"  LOC = "P28"  ; 
NET "D<6>"  LOC = "P32"  ; 
NET "D<7>"  LOC = "P33"  ; 
NET "DISEN"  LOC = "P37"  ; 
NET "G"  LOC = "P16"  ; 
NET "G_IN"  LOC = "P14"  ; 
NET "nCS"  LOC = "P40"  ; 
NET "CLK_6M"  LOC = "P42"  ; 
NET "SRAM_ADDR<0>"  LOC = "P8"  ;
NET "SRAM_ADDR<1>"  LOC = "P7"  ;
NET "SRAM_ADDR<2>"  LOC = "P6"  ;
NET "SRAM_ADDR<3>"  LOC = "P5"  ;
NET "SRAM_DATA<0>"  LOC = "P34"  ;
NET "SRAM_DATA<1>"  LOC = "P36"  ;
NET "SRAM_DATA<2>"  LOC = "P31"  ;
NET "SRAM_DATA<3>"  LOC = "P30"  ;
NET "SRAM_nWE"  LOC = "P3"  ;
NET "R"  LOC = "P19"  ; 
NET "R_IN"  LOC = "P18"  ; 
#PACE: Start of PACE Area Constraints
#PACE: Start of PACE Prohibit Constraints
#PACE: End of Constraints generated by PACE

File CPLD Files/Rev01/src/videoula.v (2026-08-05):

`timescale 1ns / 1ps
/************************************************************************
VideoULA.v
VideoULA V1    - A replacement Video ULA for the BBC Micro
Build 37       - August 2026 - Pre-load sram_addr_reg one cycle early for tSA fix
                 Based on community code by hoget (Stardot forums)
                 Posedge sampling at x111 per DRAM timing analysis
(C) Ken Lowe July 2026.
Community contributions: hoget (Stardot forums) - unified clock architecture
------------------------------------------------------------------------
CLOCK CONFIGURATION - uncomment ONE define only
NOTE: CLK_6M is always present as a port in both builds.
  48MHz build: CLK_6M actively drives the SAA5050 6MHz clock
  16MHz build: CLK_6M is held high-Z (no change to .ucf required)
The NET "CLK_6M" LOC = "P42" constraint in the .ucf can remain
active for both builds.
------------------------------------------------------------------------
Clock architecture (unified):
  A 4-bit clk_counter divides the effective 16MHz clock.
  In 16MHz mode, mhz16_clken=1 so clk_counter increments every CLK_IN tick.
  In 48MHz mode, a 2-bit prescaler divides 48MHz by 3, giving mhz16_clken
  every 3rd tick. clk_counter then behaves identically in both modes.

  CLK_8M   = clk_counter[0]  (8MHz, direct bit tap)
  CLK_4M   = clk_counter[1]  (4MHz, direct bit tap)
  CLK_2M   = clk_counter[2]  (2MHz, direct bit tap)
  CLK_1M   = clk_counter[3]  (1MHz, direct bit tap)
  CLK_CRTC = clk_counter[2] or clk_counter[3] per r0_crtc_2mhz

  CLK_6M (48MHz mode only):
    Derived from {clk_counter, clk_prescaler} state decode (CASE option).
    Phase locked to CLK_1M: CLK_6M rises 20.83ns before CLK_1M falls.
    tD = 20.83ns, within SAA5050 requirement of 6-60ns. ?

  pixel_reg sampled on posedge at end of DRAM access cycle x111:
    DRAM nCAS asserted at x110 (via IC45 74S139, ~12ns delay)
    DRAM data valid after ~67ns (55ns HM4816A-3 access + 12ns IC45)
    67ns < 125ns (2 x 62.5ns cycles) so data valid by end of x111 ?
    All logic on posedge - no mixed-edge clocking, no BUFG warnings.

Palette storage: external SRAM (IS62C256AL-45TLI)
  SRAM_ADDR[3:0] <- palette index (logical colour)
  SRAM_DATA[3:0] <-> palette data (physical colour)
  SRAM_nWE       <- write enable (active low)
  Note: SRAM write uses live CPU bus data (D[7:4] address, D[3:0] data).
        Write pulse = one 16MHz cycle = 62.5ns > IS62C256AL-45 tWP=25ns minimum ?
        SRAM_ADDR and SRAM_nWE both change simultaneously (both driven by
        sram_write), so tSA=0ns is not strictly met. Works in practice.
************************************************************************/

// ------------------------------------------------------------------------
// CLOCK CONFIGURATION - uncomment ONE define only
// ------------------------------------------------------------------------
`define CLK_48MHZ
//`define CLK_16MHZ

`ifdef CLK_48MHZ
  `ifdef CLK_16MHZ
    ERROR_BOTH_CLOCK_DEFINES_SET // deliberate syntax error if both defined
  `endif
`endif

module VideoULA (
    // Clocks
    input  wire        CLK_IN,
    output wire        CLK_8M,
    output wire        CLK_4M,
    output wire        CLK_2M,
    output wire        CLK_1M,
    output wire        CLK_CRTC,
    // 6MHz output: drives SAA5050 in 48MHz mode; high-Z in 16MHz mode
    output wire        CLK_6M,
    // Bus interface
    input  wire        nCS,
    input  wire        A,
    input  wire [7:0]  D,
    // Control interface
    input  wire        DISEN,
    input  wire        CURSOR,
    // Video in (teletext mode)
    input  wire        R_IN,
    input  wire        G_IN,
    input  wire        B_IN,
    // Video out
    output wire        R,
    output wire        G,
    output wire        B,
    // External palette SRAM interface
    output wire [3:0]  SRAM_ADDR,
    inout  wire [3:0]  SRAM_DATA,
    output wire        SRAM_nWE
);

    // -------------------------------------------------------------------------
    // ULA control register (R0) fields
    // -------------------------------------------------------------------------
    reg        r0_cursor0    = 1'b0;
    reg        r0_cursor1    = 1'b0;
    reg        r0_cursor2    = 1'b0;
    reg        r0_crtc_2mhz = 1'b0;
    reg [1:0]  r0_pixel_rate = 2'b00;
    reg        r0_teletext   = 1'b0;
    reg        r0_flash      = 1'b0;

    // -------------------------------------------------------------------------
    // Pixel shift register & CRTC display enable latch
    // -------------------------------------------------------------------------
    reg [7:0] pixel_reg  = 8'hFF;
    reg       crtc_disen = 1'b0;

    // -------------------------------------------------------------------------
    // Clock divider
    // -------------------------------------------------------------------------
    reg [3:0] clk_counter = 4'b0000;

    // mhz16_clken: enables clk_counter increment at 16MHz rate
    // 16MHz mode: always 1 (every CLK_IN tick)
    // 48MHz mode: clk_prescaler[1] (every 3rd CLK_IN tick)
    wire mhz16_clken;

`ifdef CLK_48MHZ
    reg [1:0] clk_prescaler = 2'b00;
    reg       clk_6m_reg    = 1'b0;

    // 2-bit prescaler: counts 00,01,10,00,01,10...
    // MSB (clk_prescaler[1]) becomes mhz16_clken
    always @(posedge CLK_IN) begin
        if (clk_prescaler[1])
            clk_prescaler <= 2'b00;
        else
            clk_prescaler <= clk_prescaler + 1'b1;
    end

    // CLK_6M generation from {clk_counter, clk_prescaler} state.
    // 48 states total (16 x 3). CLK_6M toggles every 4 states = 6MHz.
    // Phase locked: CLK_6M rises at state 1111_01 (20.83ns before CLK_1M falls)
    // tD = 20.83ns, within SAA5050 requirement of 6-60ns. ?
    //
    // State table (clk_counter_clk_prescaler -> clk_6m_reg action):
    // 0000_10, 0011_01, 0110_00, 1000_10, 1011_01, 1110_00 -> 0
    // 0010_00, 0100_10, 0111_01, 1010_00, 1100_10, 1111_01 -> 1
    always @(posedge CLK_IN) begin
        (* parallel_case *)
        case ({clk_counter, clk_prescaler})
            6'b000010, 6'b001101, 6'b011000,
            6'b100010, 6'b101101, 6'b111000:
                clk_6m_reg <= 1'b0;
            6'b001000, 6'b010010, 6'b011101,
            6'b101000, 6'b110010, 6'b111101:
                clk_6m_reg <= 1'b1;
            default: ; // hold current value
        endcase
    end

    assign mhz16_clken = clk_prescaler[1];
    assign CLK_6M      = clk_6m_reg;
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

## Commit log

2026-08-07 Updated value of C7 & C8
    [VideoULA.kicad_pcb, VideoULA.kicad_sch]
2026-09-03 Upload Rev02
    Rev02: Buffered / Conditioned 16MHz Clock
    [ECS-TXO-3225-250-TR.STEP, Header-Male-round 14 pin.step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]
2026-09-03 Upload Rev03
    Rev03: Buffered 8/6/4/2/1MHz clock outputs
    [BQA0014B.stp, ECS-TXO-3225-250-TR.STEP, Header-Male-round 14 pin.step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]
2026-09-04 Upload Rev04
    Rev04: Repositioned JTAG connector
    [BQA0014B.stp, ECS-TXO-3225-250-TR.STEP, Header-Male-round 14 pin.step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]

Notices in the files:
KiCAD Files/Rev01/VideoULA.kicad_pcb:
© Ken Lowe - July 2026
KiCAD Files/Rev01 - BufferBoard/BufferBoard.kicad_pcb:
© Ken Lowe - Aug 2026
